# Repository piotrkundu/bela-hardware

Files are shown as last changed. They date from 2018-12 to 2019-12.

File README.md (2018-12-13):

# bela-hardware

Hardware design files for Bela cape and capelets. PCB designs are 
made in either Cadsoft EAGLE (https://cadsoft.io) or Kicad (http://kicad-pcb.org). 

 ```
 ____  _____ _        _    
| __ )| ____| |      / \   
|  _ \|  _| | |     / _ \  
| |_) | |___| |___ / ___ \ 
|____/|_____|_____/_/   \_\
```
The platform for ultra-low latency audio and sensor processing

http://bela.io

A project of the Augmented Instruments Laboratory within the
Centre for Digital Music at Queen Mary University of London.
http://www.eecs.qmul.ac.uk/~andrewm

(c) 2016 Augmented Instruments Laboratory: Andrew McPherson,
	Astrid Bin, Liam Donovan, Christian Heinrichs, Robert Jack,
	Giulio Moro, Laurel Pardue, Victor Zappi. All rights reserved.
	
The Bela hardware is available under the Creative Commons 
Attribution-ShareAlike 3.0 Unported License:

http://creativecommons.org/licenses/by-sa/3.0/

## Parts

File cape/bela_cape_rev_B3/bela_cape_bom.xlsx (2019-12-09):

Name | Quantity | Value | Package | Description | Farnell # | Mouser # | Datasheet / Notes
 |  |  |  |  |  | 810-C1608X5R1A106M
C2-C3, C24-C27, C34 | 7 | 10uF | “0603” | Capacitor ceramic 0603 | 2309028
C12, C13, C28, C29, C32, C38 | 6 | 1uF | “0603” | Capacitor ceramic 0603 | 1710292 | 77-VJ0603V105MXQPBC
C1, C4-C11, C15, C20-C23, C35-C36, C40 | 17 | 0.1uF | “0603” | Capacitor ceramic 0603 | 1709957 | 80-C0603C104K5R
C30-C31 | 2 | 47pF | "0603" | Capacitor ceramic 0603 |  | 77-VJ0603A470JXACBC
C14, C16, C17, C39 | 4 | 47uF | "1206" | Capacitor electrolytic 1206 |  | 647-F930J476MAA
C33 | DNI
D1, D2 | 2 | TE Connectivity PESD0603-240 | "0603" | ESD suppressor 24V |  | 650-PESD0603-240
D3, D4 | 2 | BAS70-04 | SOT23-3 | Dual Schottky diode |  | 863-BAS70-04LT1G
FB1-FB4 | 4 | Ferrite bead | “0603” | Ferrite bead 0603 | 1781090 | 810-MPZ1608S121A
IC1-IC2 | 2 | OPA4348AIPWR | TSSOP-14 | Quad rail-to-rail op amp | 2323319
IC3 | 1 | AD5668 | TSSOP-16 | 16-bit DAC |  | 584-AD5668ARUZ-2
IC4 | 1 | AD7699 | LFCSP-20 | 16-bit ADC |  | 584-AD7699BCPZ
IC5 | 1 | TXB0104PWR | TSSOP-14 | Level shifter | 1607891
IC6 | 1 | TLV320AIC3104 | QFN-32 | Audio codec |  | 595-TLV320C3104IRHBR
IC7 | 1 | MIC5317 | SOT23-5 | 1.8V regulator |  | 998-MIC5317-1.8YM5TR
IC8-IC9 | 2 | LM4876 | SOIC-8 | Audio power amp |  | 926-LM4876M/NOPB
J1 | DNI | Molex 2-pin | Through Hole | 2-pin Molex KK series connector |  | 538-22-23-2025
J3, J4 | 2 | Molex 3-pin | Through Hole | 3-pin Molex KK series connector |  | 538-22-23-2031
J2 | 1 | Molex 4-pin | Through Hole | 4-pin Molex KK series connector |  | 538-22-23-2041
J5-J6 | 1 | Molex 2-pin | Through Hole | 2-pin Molex KK series connector |  | 538-22-23-2025
J7-J8 | 2 | 10-pin socket | Through Hole | 10-pin socket |  | 992-10FX1-254MM
J9-J10 | DNI
P8, P9 | 2 | Adafruit 706 (or similar) | Through Hole | 46-pin long-lead female sockets for BeagleBone |  |  | http://www.adafruit.com/product/706
R1-R2, R4 | 3 | 0 ohm | “0603” | Resistor 0603
R3, R5 | DNI
R7, R14 | 2 | 43k ohm | “0603” | Resistor 0603
R8, R10, R13 | 3 | 22k ohm | “0603” | Resistor 0603
R6, R9 | 2 | 100 ohm | “0603” | Resistor 0603
R11, R12 | 2 | 15 ohm | “0603” | Resistor 0603
R15, R16 | 2 | 3.3k ohm | “0603” | Resistor 0603
R17, R18 | 2 | 220 ohm | “0603” | Resistor 0603
R21, R22 | 2 | 2.2k ohm | “0603” | Resistor 0603
RN1-RN2 | 2 | 22 ohm 4x network | “0603” | Resistor network 4x0603 | 2060086
RN3-RN6 | 4 | 220 ohm 4x network | "0603" | Resistor network 4x0603 | 2060094
SW1 | 1 | C&K Components PTS810 SJG 250 SMTR LFS | SMD | Micro tactile switch |  | 611-PTS810SJG250SMTR
Total | 86 |  |  | Bela rev. B3

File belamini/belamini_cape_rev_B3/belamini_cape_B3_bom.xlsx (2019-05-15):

Name | Quantity | Value | Side | Package | Description | Farnell # | Mouser # | Datasheet / Notes
 |  |  |  |  |  |  | 810-C1608X5R1A106M
C2, C3, C18, C19 | 4 | 10uF | bottom | “0603” | Capacitor ceramic 0603 | 2309028
C7, C14, C15 | 3 | 1uF | bottom | “0603” | Capacitor ceramic 0603 | 2496916 | 77-VJ0603V105MXQPBC
C1, C4, C5, C6, C16, C17 | 6 | 0.1uF | bottom | “0603” | Capacitor ceramic 0603 | 1709957 | 80-C0603C104K5R
C10, C11, C12, C13 | 4 | 47pF | bottom | "0603" | Capacitor ceramic 0603 | 1759062 | 77-VJ0603A470JXACBC
C8, C9 | 2 | 47uF | bottom | "1206" | Capacitor electrolytic 1206 | 2353044 | 647-F930J476MAA
D1, D2, D3, D4 | 4 | TE Connectivity PESD0603-240 | bottom | "0603" | ESD suppressor 24V |  | 650-PESD0603-240
D5 | 1 | Lite-On LTST-C195TBJRKT | top | “0606” | blue/red LED |  | 859-LTST-C195TBJRKT | Important: check pinout of any generic equivalent part. Dot indicates the negative side (cathode).
FB1, FB2 | 4 | Ferrite bead | bottom | “0603” | Ferrite bead 0603 | 1781090 | 810-MPZ1608S121A
IC1, IC2 | 2 | TSV524 | bottom | QFN-16 | Quad op-amp |  | 511-TSV524IQ4T
IC3 | 1 | AD7699 | bottom | LFCSP-20 | 16-bit ADC |  | 584-AD7699BCPZ
IC4 | 1 | TLV320AIC3104 | bottom | QFN-32 | Audio codec |  | 595-TLV320C3104IRHBR
IC5 | 1 | MIC5317 | bottom | SOT23-5 | 1.8V regulator |  | 998-MIC5317-1.8YM5TR
IC6 | 1 | USBLC6-2SC6 | bottom | SOT23-6 | ESD suppressor for USB |  | 511-USBLC6-2SC6
J1 | 1 | 10-pin socket | top | Through Hole | 10-pin socket |  | 992-10FX1-254MM
J2 | 1 | 3-pin header | top | Through Hole | 3-pin socket |  | 855-M20-7820346
J3, J4 | 2 | Molex 3-pin | top | Through Hole | 3-pin Molex KK series connector |  | 538-22-23-2031
J5 | 1 | Amphenol 87583-3010RPALF | top | Solder Pad | USB A socket, solder pad | 1314363 | 649-87583-3010RPALF
P1, P2 | 2 | 36-pin header | top | Through Hole | 2x18 2.54mm stacking headers (10mm male pins on bottom, female sockets on top). |  |  | Important: use 10mm pin length rather than 12.5mm used on previous Bela builds
R1, R2 | 2 | 33 ohm | bottom | “0603” | Resistor 0603
R3 | 1 | 100 ohm | bottom | “0603” | Resistor 0603
R4, R5 | 2 | 560 ohm | bottom | “0603” | Resistor 0603
R6, R7 | 2 | 3.3k ohm | bottom | “0603” | Resistor 0603
RN1 | 1 | 22 ohm 4x network | bottom | “0603” | Resistor network 4x0603 | 2060086
S1 | 1 | C&K Components PTS810 SJG 250 SMTR LFS | top | SMD | Micro tactile switch |  | 611-PTS810SJG250SMTR
Total | 50
BOM rev. B3

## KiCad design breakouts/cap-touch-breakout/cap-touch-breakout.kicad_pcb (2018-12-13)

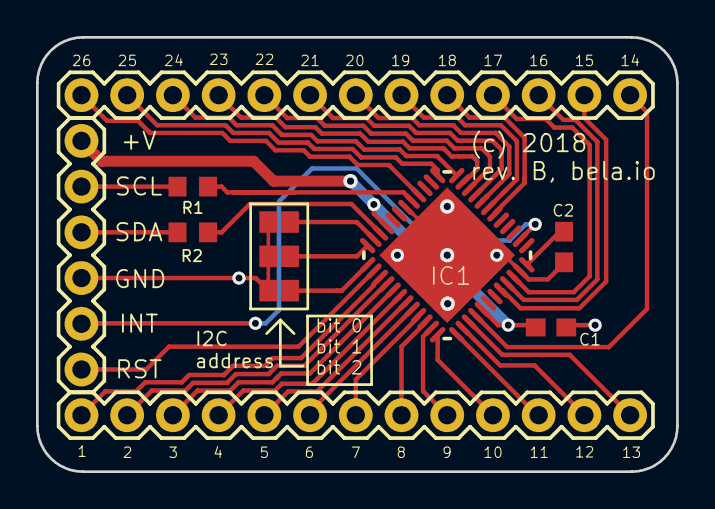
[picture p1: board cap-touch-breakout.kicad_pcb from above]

Board: 2 copper layers, 35.6 x 24.1 mm, 11 parts (0 on the bottom side), 38 nets.

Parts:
C1, C2: C-USC0603; C0603
IC1: CY8C206X6A; QFN48-LEADS
JP1: M06SILK_FEMALE_PTH; 1X06
JP3, JP4: M13; 1X13
R1, R2: R-EU_R0603; R0603
U$2, U$3, U$4: SOLDER_JUMPER

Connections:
/EVENT: IC1.2, JP1.5
/I2C_SCL: JP1.2, R1.2
/I2C_SDA: JP1.3, R2.2
/XRES: IC1.26, JP1.6
GND: C1.1, C2.2, IC1.18, IC1.47, IC1.EXP, JP1.4, U$2.P$2, U$3.P$2, U$4.P$2
unnamed: C2.1, IC1.48
unnamed: IC1.6, JP3.5
unnamed: IC1.7, JP3.6
unnamed: IC1.8, JP3.7
unnamed: IC1.9, JP3.8
unnamed: IC1.10, JP3.9
unnamed: IC1.11, JP3.10
unnamed: IC1.12, JP3.11
unnamed: IC1.13, JP3.12
unnamed: IC1.16, JP3.13
unnamed: IC1.17, R1.1
unnamed: IC1.22, R2.1
unnamed: IC1.23, U$2.P$1
unnamed: IC1.24, U$3.P$1
unnamed: IC1.25, U$4.P$1
unnamed: IC1.27, JP4.1
unnamed: IC1.28, JP4.2
unnamed: IC1.29, JP4.3
unnamed: IC1.30, JP4.4
unnamed: IC1.31, JP4.5
unnamed: IC1.32, JP4.6
unnamed: IC1.33, JP4.7
unnamed: IC1.34, JP4.8
unnamed: IC1.35, JP4.9
unnamed: IC1.36, JP4.10
unnamed: IC1.37, JP4.11
unnamed: IC1.38, JP4.12
unnamed: IC1.39, JP4.13
unnamed: IC1.40, JP3.1
unnamed: IC1.44, JP3.2
unnamed: IC1.45, JP3.3
unnamed: IC1.46, JP3.4
VCC: C1.2, IC1.21, IC1.41, JP1.1

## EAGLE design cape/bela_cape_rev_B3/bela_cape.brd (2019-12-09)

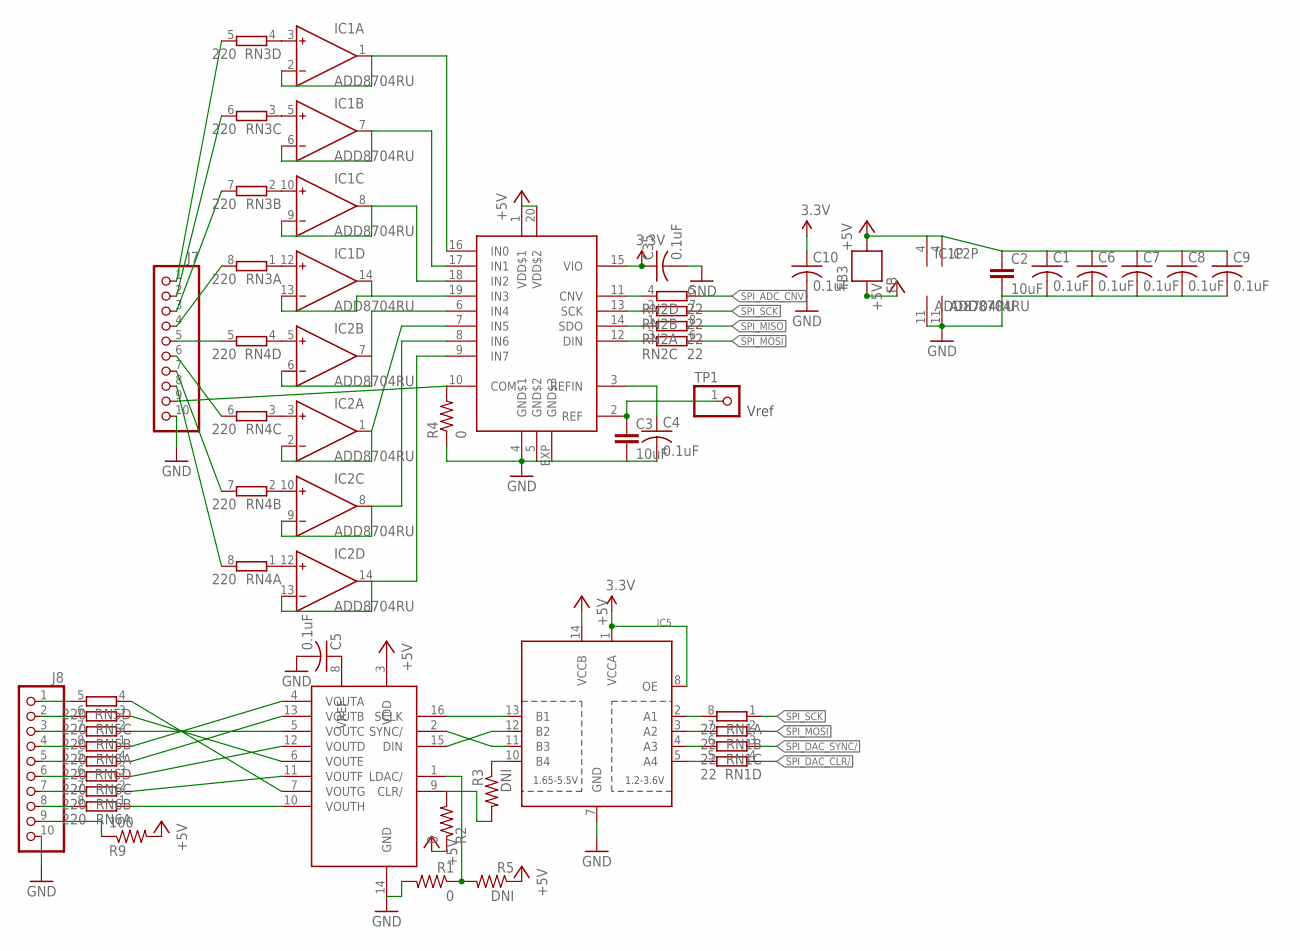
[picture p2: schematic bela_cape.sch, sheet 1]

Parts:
C1, C4, C5, C6, C7, C8, C9, C10, C35: 0.1uF; C0603
C2, C3: 10uF; 0603-CAP
FB3: FB; 0603
IC1, IC2: ADD8704RU; TSSOP14
IC3: AD5668; TSSOP16-PW
IC4: AD7699; LFCSP20-LEADS
IC5: TXB0104PWR; TSSOP14
J7, J8: PINHD-1X10; 1X10
R1, R2, R4: 0; R0603
R3, R5: DNI; R0603
R9: 100; R0603
RN1, RN2: 22; 0603-ARC
RN3, RN4, RN5, RN6: 220; 0603-ARC
TP1: PINHD-1X1; 1X01

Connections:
3.3V: C10.1, C35.1, IC4.15 (VIO), IC5.1 (VCCA), IC5.8 (OE); also elsewhere on the board
+5V_ADC_DAC: C1.1, C2.1, C6.1, C7.1, C8.1, C9.1, FB3.1, IC1.4 (V+), IC2.4 (V+), IC3.3 (VDD), IC4.1 (VDD$1), IC4.20 (VDD$2), IC5.14 (VCCB), R2.1, R5.1, R9.2
+5V_SYS: FB3.2; also elsewhere on the board
DGND: C1.2, C2.2, C3.2, C4.2, C5.2, C6.2, C7.2, C8.2, C9.2, C10.2, C35.2, IC1.11 (V-), IC2.11 (V-), IC3.14 (GND), IC4.4 (GND$1), IC4.5 (GND$2), IC4.EXP (GND$3), IC5.7 (GND), J7.10, J8.10, R1.2, R4.1; also elsewhere on the board
unnamed: IC3.16 (SCLK), IC5.13 (B1)
unnamed: IC3.15 (DIN), IC5.12 (B2)
unnamed: IC3.2 (SYNC/), IC5.11 (B3)
unnamed: IC3.9 (CLR/), R2.2, R3.2
unnamed: IC1.1 (OUT), IC1.2 (IN-), IC4.16 (IN0)
unnamed: IC1.6 (IN-), IC1.7 (OUT), IC4.17 (IN1)
unnamed: IC1.8 (OUT), IC1.9 (IN-), IC4.18 (IN2)
unnamed: IC1.13 (IN-), IC1.14 (OUT), IC4.19 (IN3)
unnamed: IC2.1 (OUT), IC2.2 (IN-), IC4.7 (IN5)
unnamed: IC2.6 (IN-), IC2.7 (OUT), IC4.6 (IN4)
unnamed: IC2.8 (OUT), IC2.9 (IN-), IC4.8 (IN6)
unnamed: IC2.13 (IN-), IC2.14 (OUT), IC4.9 (IN7)
unnamed: IC5.10 (B4), R3.1
unnamed: IC4.11 (CNV), RN2.4 (1)
unnamed: C5.1, IC3.8 (VREF)
unnamed: IC5.2 (A1), RN1.8 (2)
unnamed: IC5.3 (A2), RN1.7 (2)
unnamed: IC5.4 (A3), RN1.6 (2)
unnamed: IC5.5 (A4), RN1.5 (2)
unnamed: IC4.12 (DIN), RN2.3 (1)
unnamed: C3.1, IC4.2 (REF), TP1.1
unnamed: C4.1, IC4.3 (REFIN)
unnamed: IC4.13 (SCK), RN2.2 (1)
unnamed: IC4.14 (SDO), RN2.1
unnamed: IC4.10 (COM), J7.9, R4.2
unnamed: IC1.3 (IN+), RN3.4 (1)
unnamed: IC1.5 (IN+), RN3.3 (1)
unnamed: IC1.10 (IN+), RN3.2 (1)
unnamed: IC1.12 (IN+), RN3.1
unnamed: IC2.5 (IN+), RN4.4 (1)
unnamed: IC2.3 (IN+), RN4.3 (1)
unnamed: IC2.10 (IN+), RN4.2 (1)
unnamed: IC2.12 (IN+), RN4.1
unnamed: IC3.1 (LDAC/), R1.1, R5.2
unnamed: J7.1, RN3.5 (2)
unnamed: J7.2, RN3.6 (2)
unnamed: J7.3, RN3.7 (2)
unnamed: J7.4, RN3.8 (2)
unnamed: J7.5, RN4.5 (2)
unnamed: J7.6, RN4.6 (2)
unnamed: J7.7, RN4.7 (2)
unnamed: J7.8, RN4.8 (2)
unnamed: IC3.7 (VOUTG), RN5.4 (1)
unnamed: IC3.6 (VOUTE), RN5.3 (1)
unnamed: IC3.5 (VOUTC), RN5.2 (1)
unnamed: IC3.4 (VOUTA), RN5.1
unnamed: IC3.13 (VOUTB), RN6.4 (1)
unnamed: IC3.12 (VOUTD), RN6.3 (1)
unnamed: IC3.11 (VOUTF), RN6.2 (1)
unnamed: J8.8, RN6.8 (2)
unnamed: J8.9, R9.1
unnamed: IC3.10 (VOUTH), RN6.1
unnamed: J8.7, RN6.7 (2)
unnamed: J8.6, RN6.6 (2)
unnamed: J8.5, RN6.5 (2)
unnamed: J8.4, RN5.8 (2)
unnamed: J8.3, RN5.7 (2)
unnamed: J8.2, RN5.6 (2)
unnamed: J8.1, RN5.5 (2)
SPI_ADC_CNV: RN2.5 (2); also elsewhere on the board
SPI_DAC_CLR/: RN1.4 (1); also elsewhere on the board
SPI_DAC_SYNC/: RN1.3 (1); also elsewhere on the board
SPI_MISO: RN2.8 (2); also elsewhere on the board
SPI_MOSI: RN1.2 (1), RN2.6 (2); also elsewhere on the board
SPI_SCK: RN1.1, RN2.7 (2); also elsewhere on the board

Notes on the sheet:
Vref

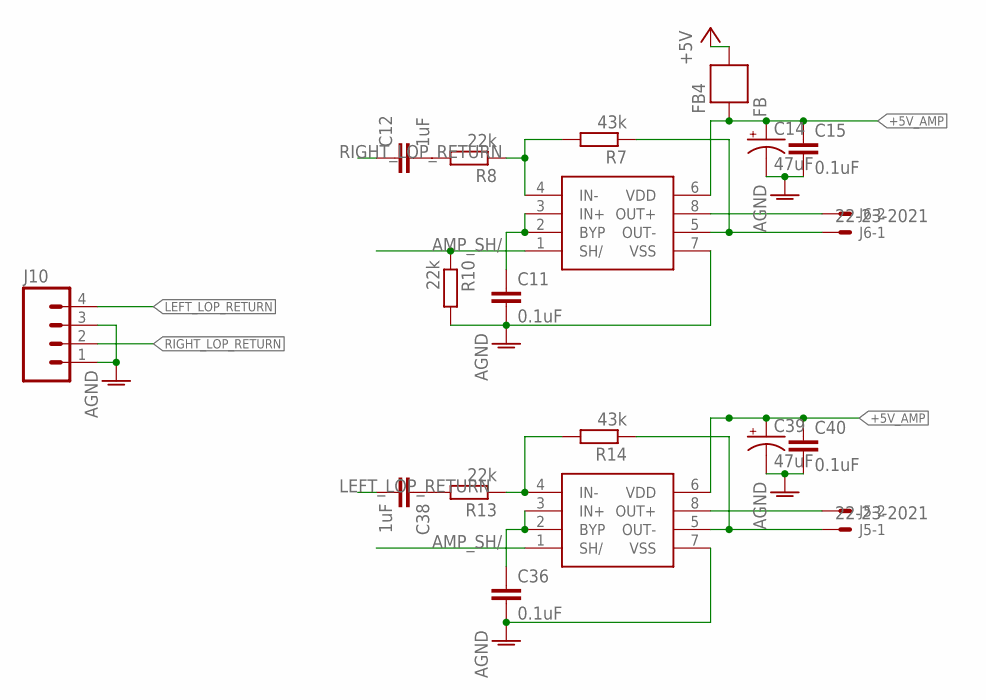
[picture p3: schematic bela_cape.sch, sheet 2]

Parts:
C11, C15, C36, C40: 0.1uF; C0603
C12, C38: 1uF; C0603
C14, C39: 47uF; EIA3216
FB4: FB; 0603
IC8, IC9: LM4876; SO8
J5, J6: 22-23-2021
J10: M04PTH; 1X04
R7, R14: 43k; R0603
R8, R10, R13: 22k; R0603

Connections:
+5V_AMP: C14.A (+), C15.1, C39.A (+), C40.1, FB4.2, IC8.6 (VDD), IC9.6 (VDD); also elsewhere on the board
+5V_POW: FB4.1; also elsewhere on the board
AGND: C11.2, C14.C (-), C15.2, C36.2, C39.C (-), C40.2, IC8.7 (VSS), IC9.7 (VSS), J10.1, J10.3, R10.2; also elsewhere on the board
AMP_SH/: IC8.1 (SH/), IC9.1 (SH/), R10.1; also elsewhere on the board
LEFT_LOP_RETURN: C38.2, J10.4
unnamed: IC9.4 (IN-), R13.1, R14.2
unnamed: IC8.4 (IN-), R7.2, R8.1
unnamed: C11.1, IC8.2 (BYP), IC8.3 (IN+)
unnamed: C12.2, R8.2
unnamed: IC8.5 (OUT-), J6.1, R7.1
unnamed: C36.1, IC9.2 (BYP), IC9.3 (IN+)
unnamed: C38.1, R13.2
unnamed: IC9.5 (OUT-), J5.1, R14.1
unnamed: IC9.8 (OUT+), J5.2
unnamed: IC8.8 (OUT+), J6.2
RIGHT_LOP_RETURN: C12.1, J10.2

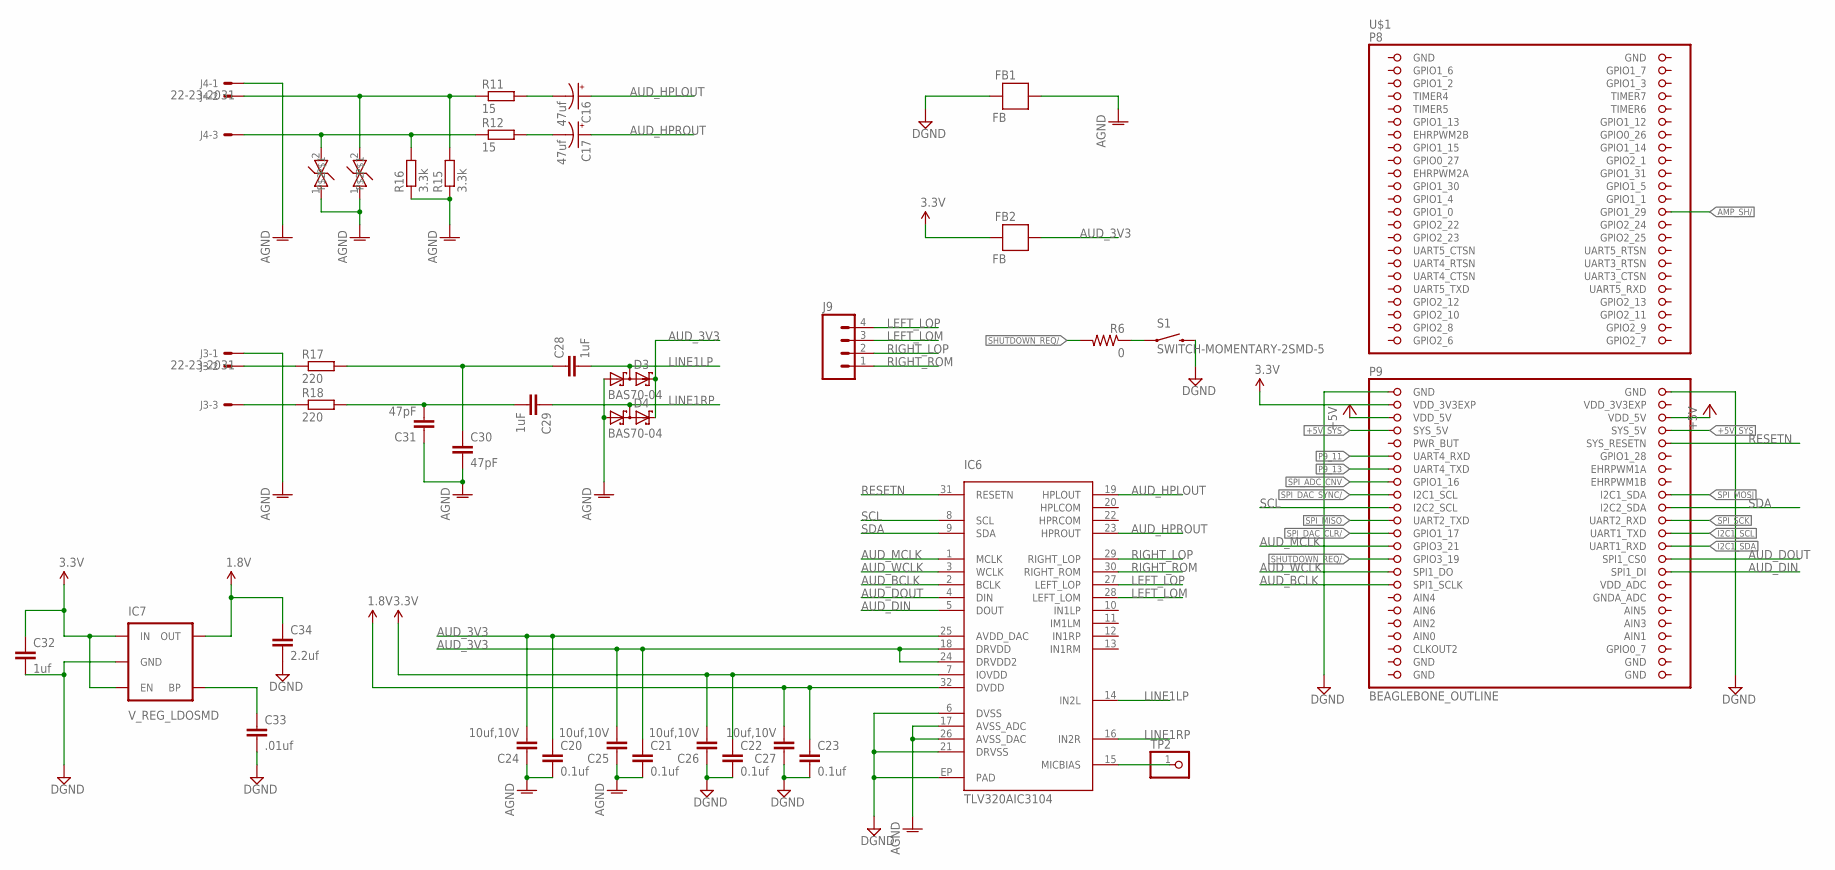
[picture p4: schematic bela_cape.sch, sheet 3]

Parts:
C16, C17: 47uf; EIA3216
C20, C21, C22, C23: 0.1uf; C0603
C24, C25, C26, C27: 10uf,10V; 0603-CAP
C28, C29: 1uF; C0603
C30, C31: 47pF; C0603
C32: 1uf; C0603
C33: .01uf; C0603
C34: 2.2uf; C0603
D1, D2: PGB0010603MR; 0603
D3, D4: BAS70-04; SOT23
FB1, FB2: FB; 0603
IC6: TLV320AIC3104; QFN-32
IC7: V_REG_LDOSMD; SOT23-5
J3, J4: 22-23-2031
J9: M04PTH; 1X04
R6: 0; R0603
R11, R12: 15; R0603
R15, R16: 3.3k; R0603
R17, R18: 220; R0603
S1: SWITCH-MOMENTARY-2SMD-5; TACTILE_SWITCH_SMD-4
TP2: PINHD-1X1; 1X01
U$1: BEAGLEBONE_OUTLINE; BEAGLEBONE_SHIELD

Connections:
1.8V: C23.1, C27.2, C34.1, IC6.32 (DVDD), IC7.5 (OUT)
3.3V: C22.1, C26.2, C32.1, FB2.2, IC6.7 (IOVDD), IC7.1 (IN), IC7.3 (EN), U$1.49 (VDD_3V3EXP); also elsewhere on the board
+5V_POW: U$1.51 (VDD_5V), U$1.52 (VDD_5V); also elsewhere on the board
+5V_SYS: U$1.53 (SYS_5V), U$1.54 (SYS_5V); also elsewhere on the board
AGND: C20.2, C21.2, C24.1, C25.1, C30.2, C31.1, D1.1, D2.1, D3.1 (A1), D4.1 (A1), FB1.1, IC6.17 (AVSS_ADC), IC6.26 (AVSS_DAC), J3.1, J4.1, R15.1, R16.1; also elsewhere on the board
AIN0: U$1.85 (AIN0)
AMP_SH/: U$1.26 (GPIO1_29); also elsewhere on the board
AUDIO_INL: C28.1, C30.1, R17.2
AUDIO_INR: C29.2, C31.2, R18.2
AUD_3V3: C20.1, C21.1, C24.2, C25.2, D3.2 (C2), D4.2 (C2), FB2.1, IC6.18 (DRVDD), IC6.24 (DRVDD2), IC6.25 (AVDD_DAC)
AUD_BCLK: IC6.2 (BCLK), U$1.77 (SPI1_SCLK)
AUD_DIN: IC6.5 (DOUT), U$1.76 (SPI1_DI)
AUD_DOUT: IC6.4 (DIN), U$1.74 (SPI1_CS0)
AUD_HPLOUT: C16.A (+), IC6.19 (HPLOUT)
AUD_HPROUT: C17.A (+), IC6.23 (HPROUT)
AUD_MCLK: IC6.1 (MCLK), U$1.71 (GPIO3_21)
AUD_WCLK: IC6.3 (WCLK), U$1.75 (SPI1_DO)
DGND: C22.2, C23.2, C26.1, C27.1, C32.2, C33.2, C34.2, FB1.2, IC6.6 (DVSS), IC6.21 (DRVSS), IC6.EP (PAD), IC7.2 (GND), S1.4 (2), U$1.1 (GND), U$1.2 (GND), U$1.47 (GND), U$1.48 (GND), U$1.89 (GND), U$1.90 (GND), U$1.91 (GND), U$1.92 (GND); also elsewhere on the board
HPL: D2.2, J4.2, R11.1, R15.2
HPR: D1.2, J4.3, R12.1, R16.2
I2C1_SCL: U$1.70 (UART1_TXD); also elsewhere on the board
I2C1_SDA: U$1.72 (UART1_RXD); also elsewhere on the board
LEFT_LOM: IC6.28 (LEFT_LOM), J9.3
LEFT_LOP: IC6.27 (LEFT_LOP), J9.4
LINE1LP: C28.2, D3.3 (C1A2), IC6.14 (IN2L)
LINE1RP: C29.1, D4.3 (C1A2), IC6.16 (IN2R)
unnamed: C16.C (-), R11.2
unnamed: IC6.15 (MICBIAS), TP2.1
unnamed: R6.1, S1.1
unnamed: C17.C (-), R12.2
unnamed: J3.2, R17.1
unnamed: C33.1, IC7.4 (BP)
unnamed: J3.3, R18.1
P9_11: U$1.57 (UART4_RXD)
P9_13: U$1.59 (UART4_TXD)
RESETN: IC6.31 (RESETN), U$1.56 (SYS_RESETN)
RIGHT_LOP: IC6.29 (RIGHT_LOP), J9.2
RIGHT_ROM: IC6.30 (RIGHT_ROM), J9.1
SCL: IC6.8 (SCL), U$1.65 (I2C2_SCL)
SDA: IC6.9 (SDA), U$1.66 (I2C2_SDA)
SHUTDOWN_REQ/: R6.2, U$1.73 (GPIO3_19)
SPI_ADC_CNV: U$1.61 (GPIO1_16); also elsewhere on the board
SPI_DAC_CLR/: U$1.69 (GPIO1_17); also elsewhere on the board
SPI_DAC_SYNC/: U$1.63 (I2C1_SCL); also elsewhere on the board
SPI_MISO: U$1.67 (UART2_TXD); also elsewhere on the board
SPI_MOSI: U$1.64 (I2C1_SDA); also elsewhere on the board
SPI_SCK: U$1.68 (UART2_RXD); also elsewhere on the board
VDD_3V3EXP: U$1.50 (VDD_3V3EXP)

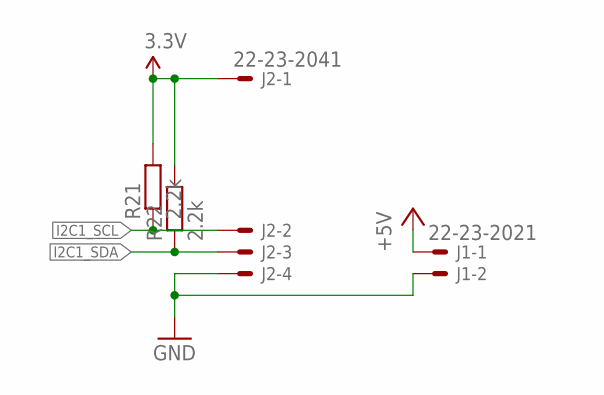
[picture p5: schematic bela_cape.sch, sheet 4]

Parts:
J1: 22-23-2021
J2: 22-23-2041
R21, R22: 2.2k; R0603

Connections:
3.3V: J2.1, R21.2, R22.2; also elsewhere on the board
+5V_AMP: J1.1; also elsewhere on the board
DGND: J1.2, J2.4; also elsewhere on the board
I2C1_SCL: J2.2, R21.1; also elsewhere on the board
I2C1_SDA: J2.3, R22.1; also elsewhere on the board

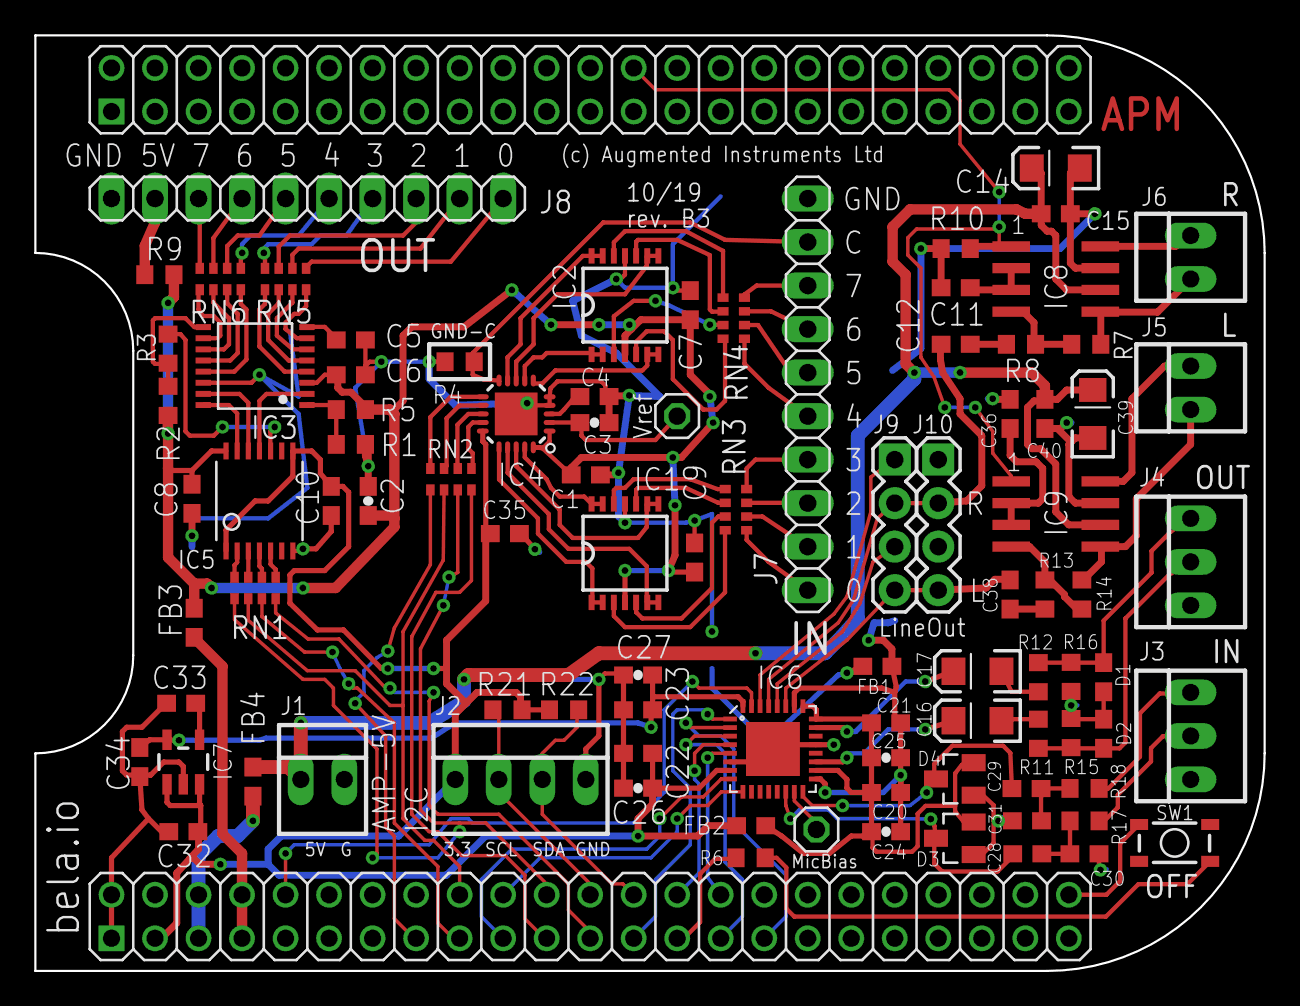
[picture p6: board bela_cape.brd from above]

Board: 2 copper layers, 71.8 x 54.6 mm, 93 parts (0 on the bottom side), 117 nets.

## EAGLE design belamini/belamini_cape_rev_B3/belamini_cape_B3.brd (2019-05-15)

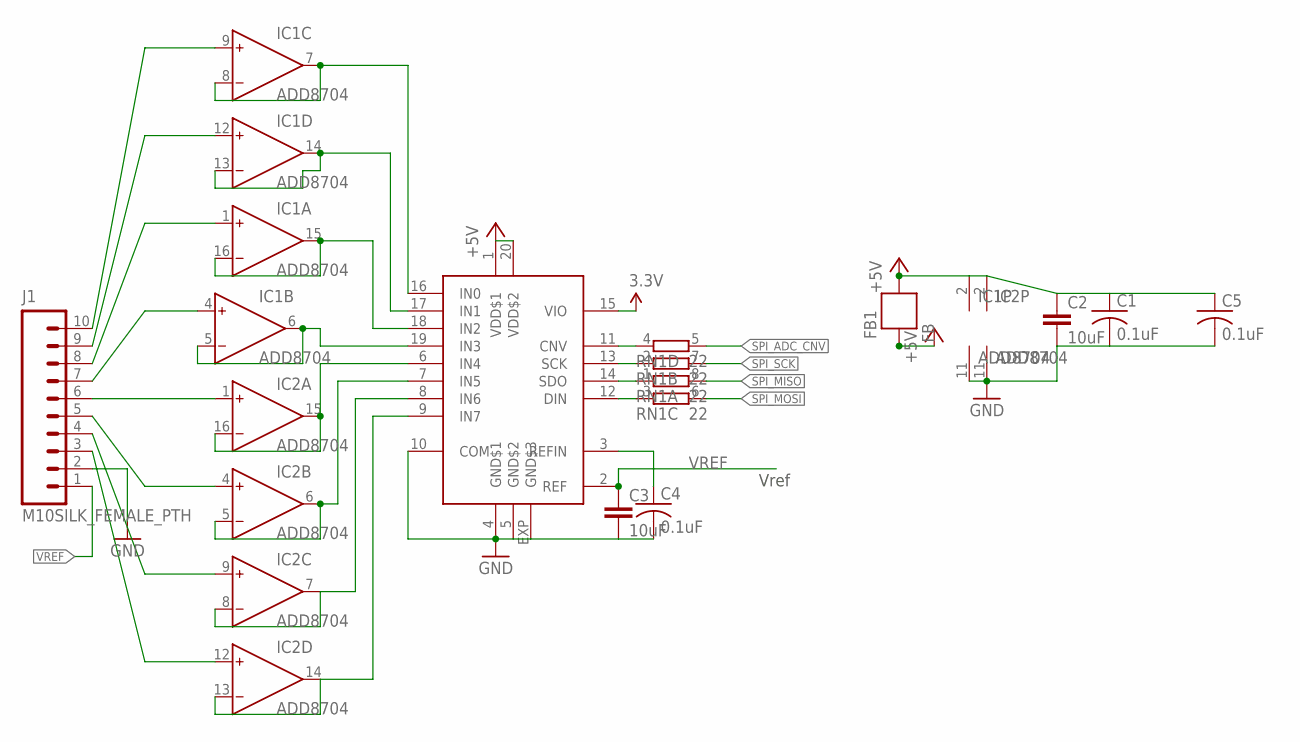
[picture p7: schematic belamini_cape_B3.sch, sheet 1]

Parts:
C1, C4, C5: 0.1uF; C0603
C2, C3: 10uF; 0603-CAP
FB1: FB; 0603
IC1, IC2: ADD8704; QFN16-3X3
IC3: AD7699; LFCSP20-LEADS
J1: M10SILK_FEMALE_PTH; 1X10
RN1: 22; 0603-ARC

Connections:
3.3V: IC3.15 (VIO); also elsewhere on the board
+5V_ADC_DAC: C1.1, C2.1, C5.1, FB1.1, IC1.2 (V+), IC2.2 (V+), IC3.1 (VDD$1), IC3.20 (VDD$2)
+5V_SYS: FB1.2; also elsewhere on the board
GND: C1.2, C2.2, C3.2, C4.2, C5.2, IC1.11 (V-), IC2.11 (V-), IC3.4 (GND$1), IC3.5 (GND$2), IC3.10 (COM), IC3.EXP (GND$3), J1.2; also elsewhere on the board
unnamed: IC2.1 (IN+), J1.6
unnamed: IC1.7 (OUT), IC1.8 (IN-), IC3.16 (IN0)
unnamed: IC1.13 (IN-), IC1.14 (OUT), IC3.17 (IN1)
unnamed: IC2.15 (OUT), IC2.16 (IN-), IC3.6 (IN4)
unnamed: IC2.5 (IN-), IC2.6 (OUT), IC3.7 (IN5)
unnamed: IC2.7 (OUT), IC2.8 (IN-), IC3.8 (IN6)
unnamed: IC2.13 (IN-), IC2.14 (OUT), IC3.9 (IN7)
unnamed: IC3.11 (CNV), RN1.4 (1)
unnamed: IC3.12 (DIN), RN1.3 (1)
unnamed: C4.1, IC3.3 (REFIN)
unnamed: IC3.13 (SCK), RN1.2 (1)
unnamed: IC3.14 (SDO), RN1.1
unnamed: IC1.5 (IN-), IC1.6 (OUT), IC3.19 (IN3)
unnamed: IC1.15 (OUT), IC1.16 (IN-), IC3.18 (IN2)
unnamed: IC1.9 (IN+), J1.10
unnamed: IC1.12 (IN+), J1.9
unnamed: IC1.1 (IN+), J1.8
unnamed: IC1.4 (IN+), J1.7
unnamed: IC2.4 (IN+), J1.5
unnamed: IC2.9 (IN+), J1.4
unnamed: IC2.12 (IN+), J1.3
SPI_ADC_CNV: RN1.5 (2); also elsewhere on the board
SPI_MISO: RN1.8 (2); also elsewhere on the board
SPI_MOSI: RN1.6 (2); also elsewhere on the board
SPI_SCK: RN1.7 (2); also elsewhere on the board
VREF: C3.1, IC3.2 (REF), J1.1

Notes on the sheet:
Vref

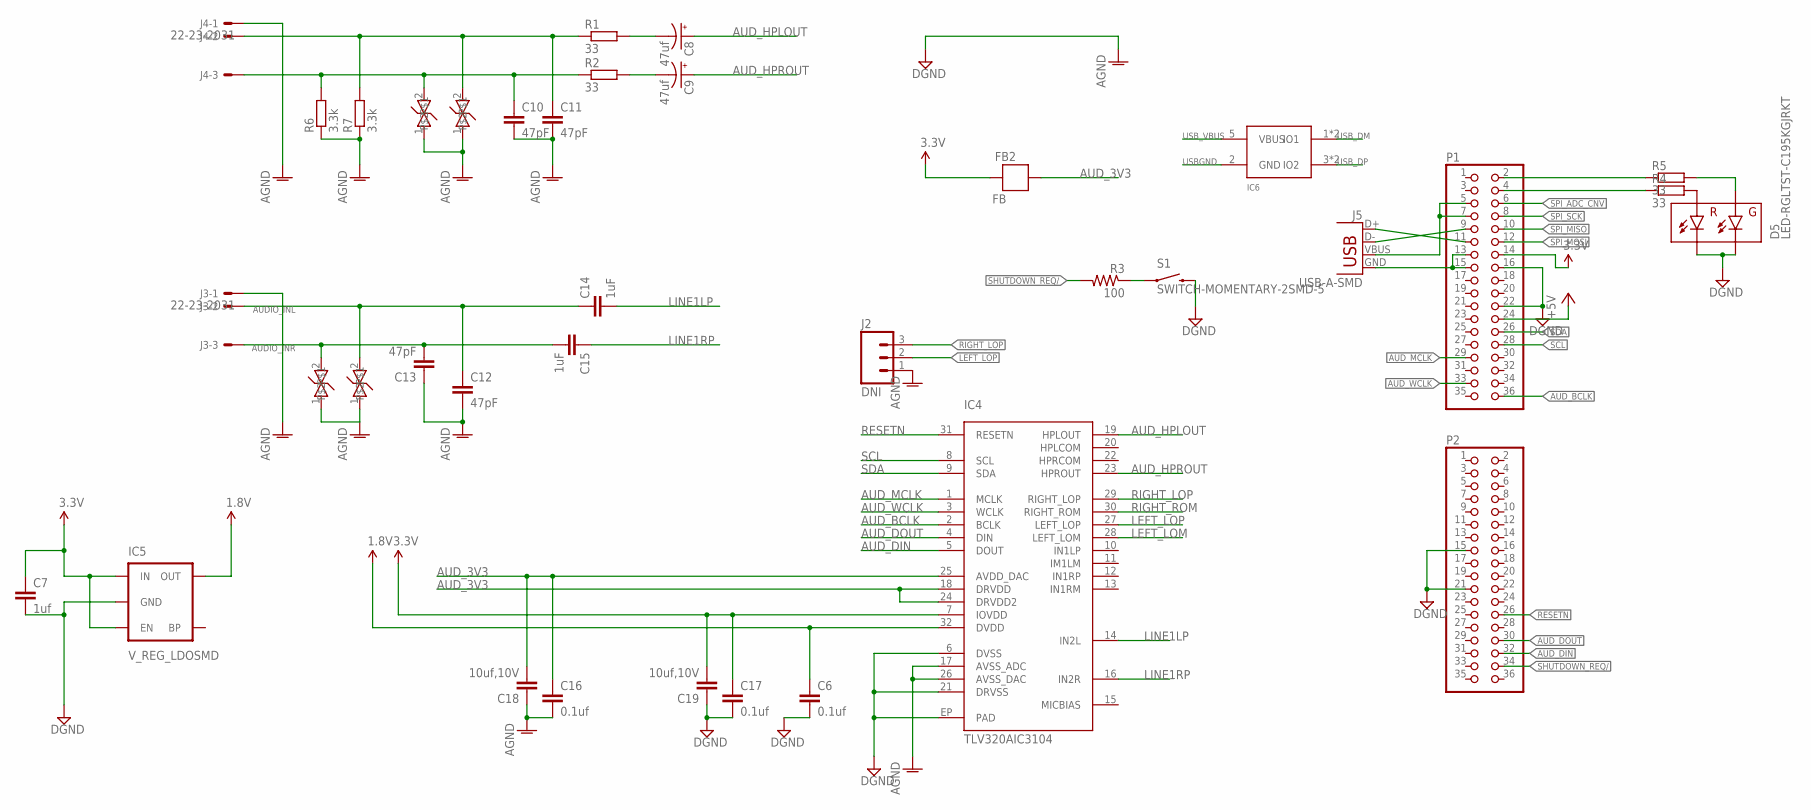
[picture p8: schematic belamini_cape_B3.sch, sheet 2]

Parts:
C6, C16, C17: 0.1uf; C0603
C7: 1uf; C0603
C8, C9: 47uf; EIA3216
C10, C11, C12, C13: 47pF; C0603
C14, C15: 1uF; C0603
C18, C19: 10uf,10V; 0603-CAP
D1, D2, D3, D4: PGB0010603MR; 0603
D5: LED-RGLTST-C195KGJRKT; LTST-C195KGJRKT
FB2: FB; 0603
IC4: TLV320AIC3104; QFN-32
IC5: V_REG_LDOSMD; SOT23-5
IC6: USBLC6-2; SOT23-6
J2: DNI; 1X03
J3, J4: 22-23-2031
J5: USB-A-SMD; USB-A-S-NOSILK-FEMALE
P1, P2: PINHD-2X18; 2X18
R1, R2, R4, R5: 33; R0603
R3: 100; R0603
R6, R7: 3.3k; R0603
S1: SWITCH-MOMENTARY-2SMD-5; TACTILE_SWITCH_SMD-4

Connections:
1.8V: C6.1, IC4.32 (DVDD), IC5.5 (OUT)
3.3V: C7.1, C17.1, C19.2, FB2.2, IC4.7 (IOVDD), IC5.1 (IN), IC5.3 (EN), P1.14; also elsewhere on the board
+5V_SYS: P1.24; also elsewhere on the board
AUDIO_INL: C12.1, C14.1, D4.2, J3.2
AUDIO_INR: C13.2, C15.2, D3.2, J3.3
AUD_3V3: C16.1, C18.2, FB2.1, IC4.18 (DRVDD), IC4.24 (DRVDD2), IC4.25 (AVDD_DAC)
AUD_BCLK: IC4.2 (BCLK), P1.36
AUD_DIN: IC4.5 (DOUT), P2.32
AUD_DOUT: IC4.4 (DIN), P2.30
AUD_HPLOUT: C8.A (+), IC4.19 (HPLOUT)
AUD_HPROUT: C9.A (+), IC4.23 (HPROUT)
AUD_MCLK: IC4.1 (MCLK), P1.29
AUD_WCLK: IC4.3 (WCLK), P1.33
GND: C6.2, C7.2, C10.2, C11.2, C12.2, C13.1, C16.2, C17.2, C18.1, C19.1, D1.1, D2.1, D3.1, D4.1, D5.P$3 (GC), D5.P$4 (RC), IC4.6 (DVSS), IC4.17 (AVSS_ADC), IC4.21 (DRVSS), IC4.26 (AVSS_DAC), IC4.EP (PAD), IC5.2 (GND), J2.1, J3.1, J4.1, P1.16, P1.22, P2.15, P2.21, R6.1, R7.1, S1.4 (2); also elsewhere on the board
HPL: C11.1, D2.2, J4.2, R1.1, R7.2
HPR: C10.1, D1.2, J4.3, R2.1, R6.2
LEFT_LOM: IC4.28 (LEFT_LOM)
LEFT_LOP: IC4.27 (LEFT_LOP), J2.2
LINE1LP: C14.2, IC4.14 (IN2L)
LINE1RP: C15.1, IC4.16 (IN2R)
unnamed: D5.P$2 (RA), R4.2
unnamed: D5.P$1 (GA), R5.2
unnamed: P1.4, R4.1
unnamed: P1.2, R5.1
unnamed: C8.C (-), R1.2
unnamed: R3.1, S1.1
unnamed: C9.C (-), R2.2
RESETN: IC4.31 (RESETN), P2.26
RIGHT_LOP: IC4.29 (RIGHT_LOP), J2.3
RIGHT_ROM: IC4.30 (RIGHT_ROM)
SCL: IC4.8 (SCL), P1.28
SDA: IC4.9 (SDA), P1.26
SHUTDOWN_REQ/: P2.34, R3.2
SPI_ADC_CNV: P1.6; also elsewhere on the board
SPI_MISO: P1.10; also elsewhere on the board
SPI_MOSI: P1.12; also elsewhere on the board
SPI_SCK: P1.8; also elsewhere on the board
USBGND: IC6.2 (GND), J5.GND, P1.13, P1.15
USB_DM: IC6.1 (IO1), IC6.6 (IO1), J5.D-, P1.9
USB_DP: IC6.3 (IO2), IC6.4 (IO2), J5.D+, P1.11
USB_VBUS: IC6.5 (VBUS), J5.VBUS, P1.5, P1.7

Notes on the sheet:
IC6

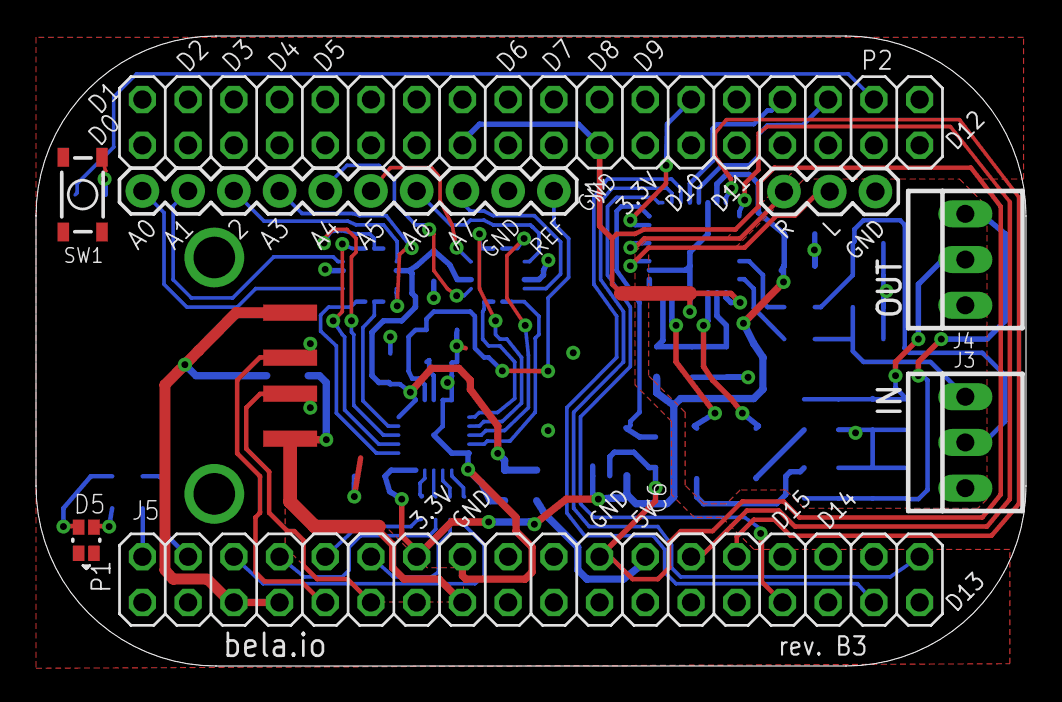
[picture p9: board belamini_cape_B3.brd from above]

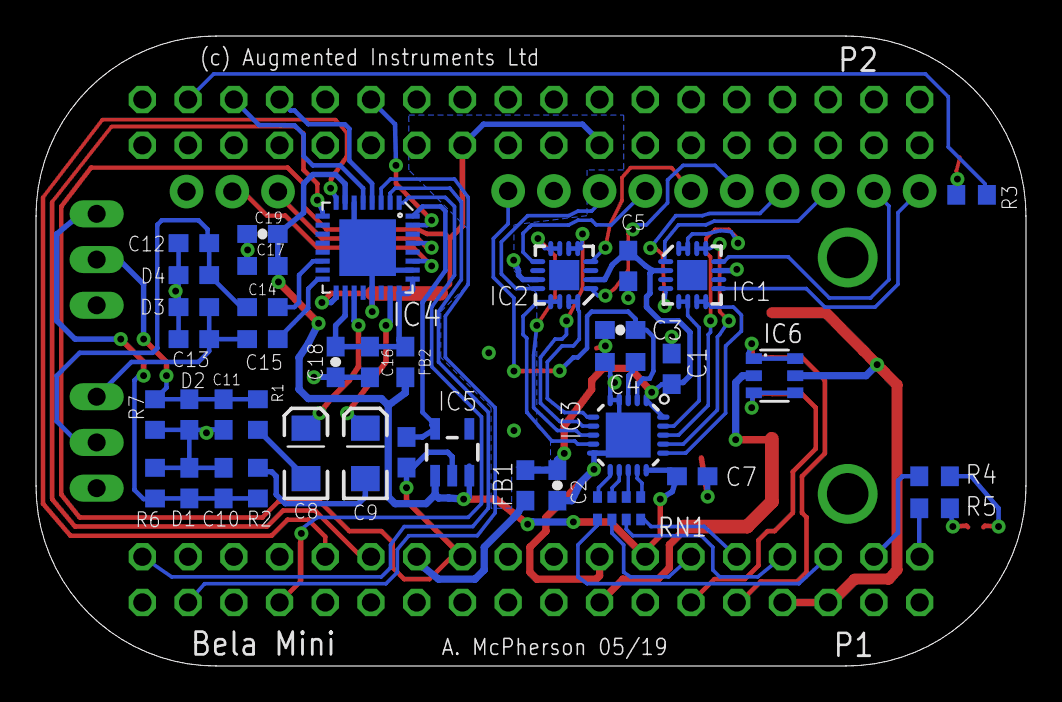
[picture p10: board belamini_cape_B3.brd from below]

Board: 2 copper layers, 55.0 x 35.0 mm, 48 parts (39 on the bottom side), 62 nets.

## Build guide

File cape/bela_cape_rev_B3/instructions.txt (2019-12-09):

Part: bela_cape, revision B3
--------------------------------

Audio and sensor cape for BeagleBone Black, featuring stereo audio codec, 8 channel 16-bit ADC, 8 channel 16-bit DAC and 2x 1.1W speaker amplifiers. Designed for the Bela ultra-low-latency audio environment.

http://bela.io

(c) 2019 Andrew McPherson 
Augmented Instruments Ltd
327 Mile End Road
London E1 4NS
United Kingdom

a.mcpherson@qmul.ac.uk

-------------------------

Suggested build specifications:

2 layers
1.6mm board thickness
black soldermask
white silkscreen, top side
standard finish
7 mil minimum feature size
15 mil minimum drill
Tab routing / milling (for panelising)

-------------------------

Package contents:

*** EAGLE Design Files:

bela_cape.sch	EAGLE schematic
bela_cape.brd	EAGLE board

*** Gerbers (RS274X unless otherwise noted):

bela_cape.cmp	Component Side (top) copper
bela_cape.sol	Solder Side (bottom) copper
bela_cape.stc	Component side (top) stop mask
bela_cape.sts	Solder side (bottom) stop mask
bela_cape.plc	Component side (top) silkscreen
bela_cape.dim	Outline dimension
bela_cape.drd	NC Drill (Excellon format)
bela_cape.crc	Component side (top) paste

*** Assembly files:

bela_cape_centroid.csv	XYRS placement data
bela_cape_bom.xls	Bill of materials

-------------------------

This design is derived from the BeagleBone Audio Cape rev. B from CircuitCo: 

http://elinux.org/CircuitCo:Audio_Cape_RevB

This design is available under the Creative Commons Attribution-ShareAlike 3.0 Unported License:

http://creativecommons.org/licenses/by-sa/3.0/

-------------------------

Revision History:

A1 (January 2015)	Internal build.
A2 (May 2015)		First public release. Revised and clarified silkscreen text.
A3 (May 2015)		Fixed soldermask on IC4.
A4 (October 2015)	Replaced J1 with a header for +5V to amps (left DNI in BOM).
			Moved FB4 next to J1 so it can be removed to disconnect +5V.
			The above changes allow amp to be powered separately from BBB/G.
			Changed J7 and J8 to sockets rather than pins.
B1 (March 2016)		Moved J7, J8, J9, J10 to align to 0.1" spacing.
			Added SW1 and R6 for a system shutdown request feature.
			Moved J3-J6 upward slightly to make room for SW1.
			Added test point for Vref on ADC.
			Fixed incorrect labels on J2.
			Changed order of DAC channels on label for J8 (needs to be
			matched with a software change).
			Added better labelling on connectors throughout.
			Changed name to Bela and website to bela.io.
			Added Bela logo on silkscreen.
B2 (September 2017)	Changed C28 and C29 from 0.1uF to 1uF.
			Connected unused pins of J10 to ground.
			Added test point for MICBIAS signal on IC6.
B3 (October 2019)	Changed protection circuit on analog inputs to use Schottky
			diodes to 3.3V and ground rather than ESD protectors.
			Changed power amp feedback resistors R7 and R14 to 43k,
			doubling gain of the amplifiers.
			Reduced headphone resistors R11 and R12 to 15 ohms, increasing
			gain for low impedance headphones.
			Added pulldown resistors on headphone outputs in place of 47pF
			capacitors.
			Silkscreen updated for latest Bela logo and copyright.

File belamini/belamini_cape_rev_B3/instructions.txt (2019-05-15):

Part: belamini_cape, revision B3
--------------------------------

Audio and sensor cape for PocketBeagle, featuring stereo audio codec, 8 channel 16-bit ADC and USB port. Designed for the Bela ultra-low-latency audio environment.

http://bela.io

(c) 2019 Augmented Instruments Ltd 
London, United Kingdom

info@bela.io

-------------------------

Suggested build specifications:

2 layers
1.6mm board thickness
black soldermask
white silkscreen, both sides
standard finish
7 mil minimum feature size
15 mil minimum drill
Tab routing / milling (for panelising)
Double-sided SMT assembly

-------------------------

Package contents:

*** EAGLE Design Files:

belamini_cape_B3.sch	EAGLE schematic
belamini_cape_B3.brd	EAGLE board

*** Gerbers (RS274X unless otherwise noted):

belamini_cape_B3.cmp	Component Side (top) copper
belamini_cape_B3.sol	Solder Side (bottom) copper
belamini_cape_B3.stc	Component side (top) stop mask
belamini_cape_B3.sts	Solder side (bottom) stop mask
belamini_cape_B3.plc	Component side (top) silkscreen
belamini_cape_B3.pls	Solder side (bottom) silkscreen
belamini_cape_B3.dim	Outline dimension
belamini_cape_B3.drd	NC Drill (Excellon format)
belamini_cape_B3.crc	Component side (top) paste
belamini_cape_B3.crs	Solder side (bottom) paste

*** Assembly files:

belamini_cape_B3_centroid.csv	XYRS placement data
belamini_cape_B3_bom.xls	Bill of materials

-------------------------

This design is available under the Creative Commons Attribution-ShareAlike 3.0 Unported License:

http://creativecommons.org/licenses/by-sa/3.0/

-------------------------

Revision History:

A1 			Internal build.
B1 			Internal build. Flip components to solder side.
B2 (March 2018)		First public release. Add ESD protection to USB port
			and ground USB ID bit. Changes to silkscreen.
B3 (May 2019)		Add R6 and R7 to reduce noise on audio output when
			codec is not active.

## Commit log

2018-12-13 Added Kicad design files for CapTouch breakout boards
    [cap-touch-breakout.kicad_pcb, cap-touch-breakout.sch, cap-touch-breakout_v2.kicad_pcb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]
2018-12-13 Modified readme to also include Kicad as cad software used for the designs
2019-05-15 Rev. B3 of the Bela Mini cape adds resistors R6 and R7 to reduce the noise when the audio output is driving a DI box and the codec is not active.
    [belamini_cape_B3.brd, belamini_cape_B3.sch, belamini_cape_B3_bom.xlsx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]
2019-12-09 Added rev. B3 of the Bela cape
    [bela_cape.brd, bela_cape.sch, bela_cape_bom.xlsx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]

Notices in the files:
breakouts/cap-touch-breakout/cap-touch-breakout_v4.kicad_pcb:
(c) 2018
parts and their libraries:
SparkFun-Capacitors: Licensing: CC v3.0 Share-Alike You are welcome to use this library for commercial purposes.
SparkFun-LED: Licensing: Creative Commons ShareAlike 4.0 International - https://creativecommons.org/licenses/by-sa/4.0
